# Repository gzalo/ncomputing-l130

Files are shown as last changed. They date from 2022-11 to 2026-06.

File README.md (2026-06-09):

# Ncomputing-L130
The idea of this project is to reverse engineer the Ncomputing L130 PCB (rev 1.3A), to be able to use it as a generic FPGA development board.

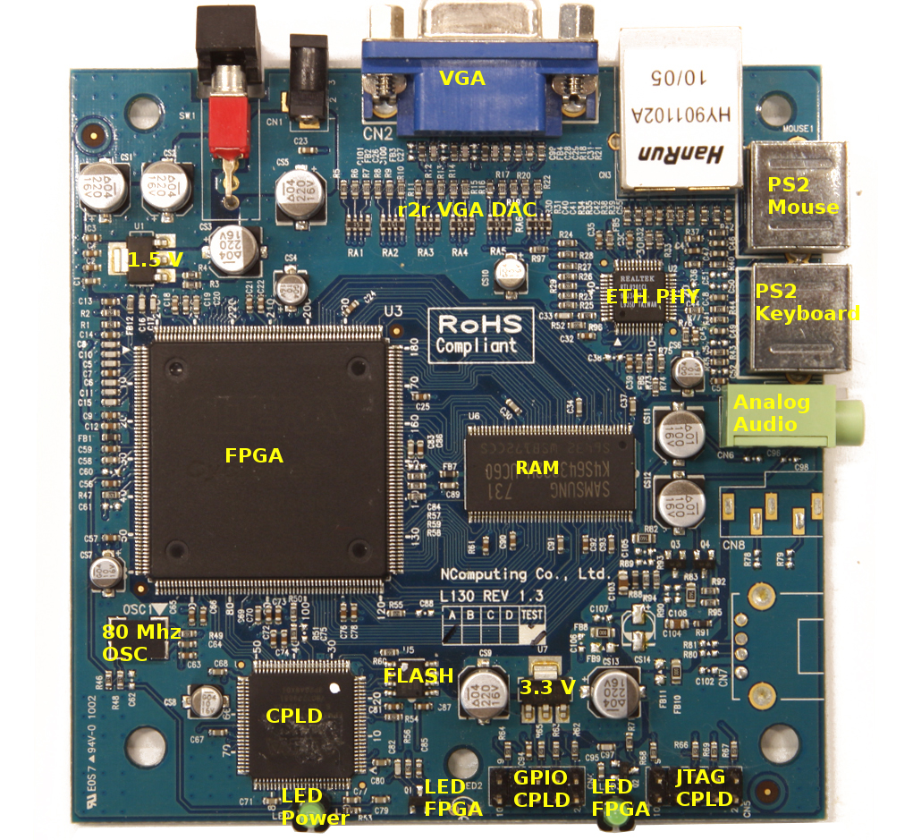
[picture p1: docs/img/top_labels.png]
Labels


Status:
- ✅ [Reverse engineer main components and connections](pcb/)
- ✅ [Basic Blinky test for CPLD](cpld_passthrough/)
- ✅ [Using Passive Serial Configuration for loading FPGA bitstream (CPLD passes through programming signals to FPGA)](cpld_passthrough/)
- ✅ [Reverse engineer full board](pcb/)
- ✅ [Blinky in FPGA](fpga_blink/)
- ✅ [VGA output](fpga_blink/)
- ✅ [Retrocomputing using multicomp](multicomp/)
- ✅ [Program flash memory using external RP2040](rp2040_flash_memory/)
- ✅ [Persist FPGA bitstream in serial flash](cpld_flash_boot/)
- ❌ Serial port 
- ❌ Sound output
- ❌ Keyboard and mouse
- ❌ SDRAM controller
- ❌ Ethernet

# Schematic, component list and PCB photos

[PDF of the Schematic](docs/img/pcb.pdf)

KiCad files can be found in the `pcb/` folder.

[Full component list here (may be missing some values, or have errors)](docs/components.csv)

[PCB Top layer](docs/img/top.jpg) / [PCB Bottom layer](docs/img/bottom.jpg)

# Block diagram

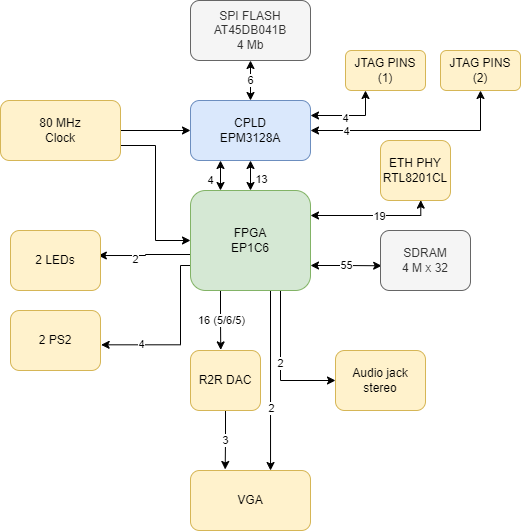
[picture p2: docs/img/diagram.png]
Block diagram


# Projects 

The following folders contain `vhd` files that can be used to create a _Quartus II_ project for this board:
- cpld_passthrough: This generates a CPLD bitstream that makes it work as a passthrough so we can send the signals required for programming the FPGA.
- cpld_flash_boot: This generates a CPLD bitstream that reads an already-programmed AT45DB041B serial flash, configures the FPGA on startup, and then passes the Passive Serial programming header through to the FPGA.
- fpga_blink: Blinks the LEDs that are connected to the FPGA.
- fpga_vga: Generates a 640x480 VGA signal that has some characters of a 32x32 monochromatic font. Uses an internal PLL to convert the 80 MHz clock into the 25 MHz pixel clock required.
- multicomp: Details on mods to Grant Searle's guide to create a retro computer

[Getting started: guide to building the projects and programming the board](docs/getting-started.md)

Newer Windows note: USB Blaster clones no longer work reliably due to driver issues. Using a Windows XP virtual machine with USB passthrough is a better option for programming.

# Flex PCB to add GPIOs
In the [`pin-flex`](pin-flex) folder you can find files to manufacture a very simple flexible PCB that is useful to map out certain unused pins:

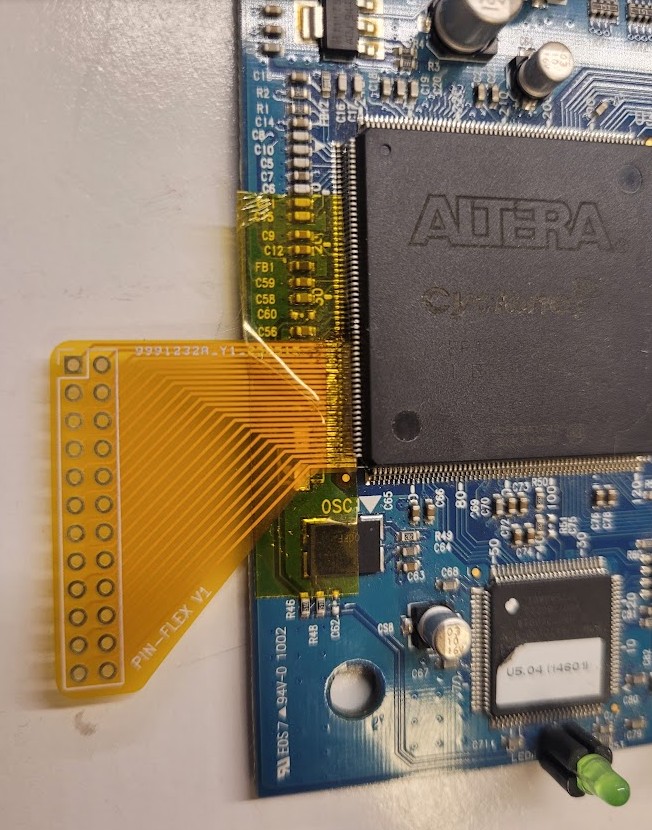
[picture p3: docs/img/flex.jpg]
Flex


To use it, you need to remove R47 and C61, and lift the existing pins using a needle or something similar, while keeping pin 40, 51 and 52 connected to the original board.

# Documentation

The [docs](docs/) folder contains many documents that are useful for this project.

**When using Quartus to generate the bitstream, remember that by default non defined pins are marked as outputs and are LOW. This can cause short circuits and destroy the rest of the circuit. To avoid that, you should go to Assignments->Device->Device and Pin Options...->Unused Pins and set it to "As input tri-stated with weak pull-up". DO THIS FOR BOTH PROJECTS!**

# Thanks to
[Carlos Pantelides (cpantel)](https://github.com/cpantel/)

# Inspirations
- https://github.com/UzixLS/ncomputing-l230

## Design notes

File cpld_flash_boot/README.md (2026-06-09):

# CPLD flash boot

This CPLD image configures the FPGA from the on-board AT45DB041B serial flash at power-up.

The FPGA is still configured in Passive Serial mode. During power-up, the CPLD acts as the configuration controller:

1. Hold `nCONFIG` low while the FPGA finishes power-on reset.
2. Release `nCONFIG`.
3. Send an AT45DB041B continuous array read command from byte address 0.
4. Stream each byte read to the FPGA `DATA0` while clocking `SCK` and `DCLK`, reversing the bit order.
5. Stop when `CONF_DONE` rises, then send a few extra `DCLK` pulses and deselect the flash.
6. Pass the external Passive Serial programming header through to the FPGA so it can still be programmed manually.

The flash is expected to already contain the FPGA bitstream starting at byte address 0. 

## Implementation notes

Use `cpld_flash_boot.vhd` as the Quartus top-level design. Add
`cpld_flash_boot.sdc` to the Quartus project so the clock and multicycle timing
constraints are applied.

The CPLD uses the 80 MHz board clock on pin 87 and drives the AT45DB041B with
the Continuous Array Read, High Frequency Mode command:

```text
0B 00 00 00 00 -> data...
```

The CPLD generates a global clock-enable pulse every 8 cycles of the 80 MHz
input clock. The boot sequencer only advances on that enable. Because `SCK` and
`DCLK` each spend one enable tick low and one enable tick high, the serial
clocks are 5 MHz. The CPLD keeps `nCONFIG` low and leaves the flash deselected
for about 26 ms after startup before issuing the read command. Each flash byte
is read MSB-first from `SO`, then sent to the FPGA `DATA0` LSB-first with
separate `DCLK` pulses. After `CONF_DONE` rises, the CPLD sends 64 extra `DCLK`
pulses, deselects the flash, and switches `DATA0`, `nCONFIG`, `DCLK`, and
open-drain `CONF_DONE` over to the same header pins used by `cpld_passthrough`.

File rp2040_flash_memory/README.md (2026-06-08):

# RP2040 flash programmer

This directory contains a small MicroPython helper for programming the
AT45DB041D SPI flash used by this project.

## Why use the RP2040

Programming this flash with XGecu/TL866II was not reliable. The programmer
detects the memory incorrectly: the first manufacturer/device ID byte is read as
`0x1E` instead of `0x1F`.

Adding resistors and capacitors on the clock and SO lines did not fix the
problem reliably. The programmer also seems to have trouble selecting between
the 256-byte and 264-byte page modes, so programming may work but verifies
incorrectly.

## Programming flow

1. Install MicroPython on the RP2040 board.
2. Copy `flash.py` and the generated `.rbf` file to the RP2040 filesystem.
3. In Quartus, generate the `.rbf` file from the project output:
   `File -> Convert Programming Files`.
4. Open the MicroPython REPL and run:

```python
import flash
flash.program_file("output_file.rbf")
```

The script currently assumes 256-byte page mode (it appears to be the default
in our boards) and uses the pinout documented at the top of `flash.py`.

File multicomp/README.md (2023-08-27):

# Multicomp

[Multicomp is a guide made by Grant Searle](http://searle.x10host.com/Multicomp/index.html) which can be used to create a retrocomputing environment using an FPGA. 
There are a few things that need to be considered when following his guide. I've only tried Z80 with BASIC ROM, and soon I'll likely upload a ready to use version of his code that works with our board.

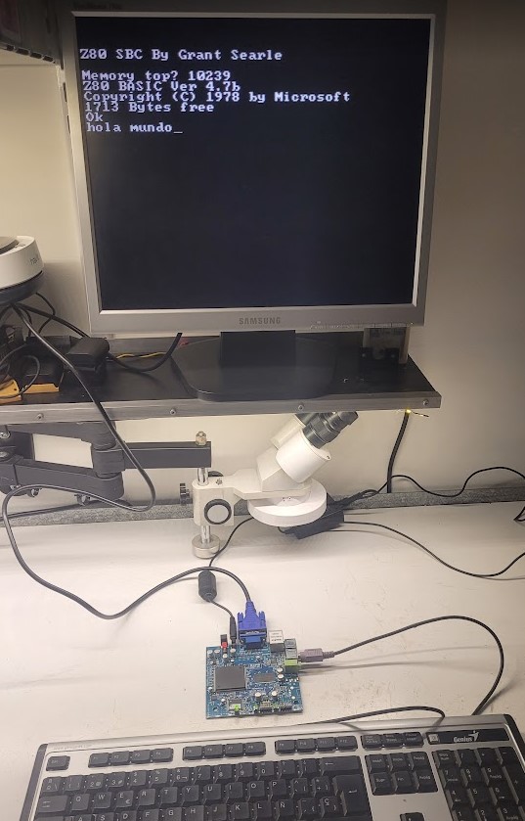
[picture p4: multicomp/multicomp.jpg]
Multicomp working in our board


## Memory
The FPGA he uses has more internal memory (13 KB total vs 10.2 KB in ours) so there are a few things that don't really fit. We need at least:

- 8 KiB for the Z80 BASIC ROM (0x0000-0x2000)
- 1 KiB for the reduced character ROM (128*8 bytes)
- 2 KB for the character video memory (40x25x2 bytes)
- 2 KiB for system RAM that can be used in BASIC (0x2000-0x27FF)

As it can be seen, to fit that minimal system we would need a bigger FPGA, as it sums up to 13 KB. But we can do a trick and split the Z80 ROM into two. First 5120 bytes can be implemented using the internal memory, and the rest of the ROM can be implemented as logic elements. This increases the logic usage a lot (and it takes a lot more time to synthesize too) and it almost doesn't fit, but it works just fine. I had to create a simple program to do this split as it's not supported natively.

Unfortunately our board doesn't have readily available pins for connecting an external static RAM. We could use the external DRAM but it will need an additional controller to use it as a SRAM, still haven't had much time to look into that.

## Cyclone model
Some of his autogenerated VHD files (mostly the ones related to memories) are suited to a Cyclone II board, so they need to change or they won't even compile. Running the IP wizard on those and generating them again should work fine.

## Clock
His design expects the clock to be a 50 MHz signal, so there are a few things that won't work directly unless we change that. The easiest way is to include a PLL that turns the external 80 MHz into the expected one.

## Pins for serial UART
Since we have unused pins, it is possible to connect them to an external UART to use it instead of a keyboard. Since they aren't wired in the board it may be a bit harder to connect to them directly as the FPGA has pins with a 0.5mm pitch. It may be possible to use a modded SMD adapter to do so, lifting the unused pins and soldering them in a board, then fixing that board with resin for mecanical strength (pending investigation).

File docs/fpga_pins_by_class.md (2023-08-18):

# FPGA pins by class

## Audio
- 1
- 2

## Clock
- 28
- 153

## To CPLD (programming)
- 25 (DATA0) to CPLD_68
- 26 (nCONFIG) to CPLD_67
- 36 (DCLK) to CPLD_63 via 82 ohms
- 145 (CONF_DONE) to CPLD_16

## To CPLD (general purpose)
- 73 to CPLD_50
- 74 to CPLD_49
- 79 to CPLD_47
- 80 to CPLD_46
- 81 to CPLD_45
- 83 to CPLD_44
- 86 to CPLD_42
- 87 to CPLD_41
- 88 to CPLD_40
- 94 to CPLD_32
- 95 to CPLD_31
- 96 to CPLD_30
- 97 to CPLD_29

## LEDs
- 85 to LED3
- 93 to LED2

## Ethernet
- 100 to ETH_42 RESETB
- 101 to ETH_46 X1
- 134 to ETH_4 TXD2
- 135 to ETH_5 TXD1
- 136 to ETH_6 TXD0
- 137 to ETH_7 TXC
- 138 to ETH_16 RXC
- 139 to ETH_18 RXD3
- 140 to ETH_19 RXD2
- 141 to ETH_20 RXD1
- 143 to ETH_21 RXD0
- 144 to ETH_22 RXDV
- 156 to ETH_23 CRS
- 180 to ETH_24 FXER/FXEN
- 198 to ETH_3 TXD3
- 199 to ETH_2 TXEN
- 200 to ETH_1 COL
- 201 to ETH_25 MDC
- 202 to ETH_26 MDIO

## RAM
- 177 to MEM_24 A10
- 116 to MEM_66 A9
- 117 to MEM_62 A5
- 118 to MEM_63 A6
- 119 to MEM_65 A8
- 120 to MEM_64 A7
- 121 to MEM_61 A4
- 122 to MEM_60 A3
- 174 to MEM_27 A2
- 175 to MEM_26 A1
- 176 to MEM_25 A0

- 178 to MEM_23 BA1
- 179 to MEM_22 BA0

- 123 to MEM_59 DQM3
- 173 to MEM_28 DQM2
- 114 to MEM_71 DQM1
- 185 to MEM_16 DQM0

- 124 to MEM_56 DQ31
- 125 to MEM_54 DQ30
- 126 to MEM_53 DQ29
- 127 to MEM_51 DQ28
- 128 to MEM_50 DQ27
- 131 to MEM_48 DQ26
- 132 to MEM_47 DQ25
- 133 to MEM_45 DQ24
- 158 to MEM_42 DQ23
- 159 to MEM_40 DQ22
- 160 to MEM_39 DQ21
- 161 to MEM_37 DQ20
- 162 to MEM_36 DQ19
- 163 to MEM_34 DQ18
- 164 to MEM_33 DQ17
- 165 to MEM_31 DQ16
- 102 to MEM_85 DQ15
- 103 to MEM_83 DQ14
- 104 to MEM_82 DQ13
- 105 to MEM_80 DQ12
- 106 to MEM_79 DQ11
- 107 to MEM_77 DQ10
- 108 to MEM_76 DQ9
- 113 to MEM_74 DQ8
- 186 to MEM_13 DQ7
- 187 to MEM_11 DQ6
- 188 to MEM_10 DQ5
- 193 to MEM_8 DQ4
- 194 to MEM_7 DQ3
- 195 to MEM_5 DQ2
- 196 to MEM_4 DQ1
- 197 to MEM_2 DQ0

- 115 to MEM_68 CLK
- 181 to MEM_17 !WE
- 182 to MEM_18 !CAS
- 183 to MEM_19 !RAS
- 184 to MEM_20 !CS

## VGA
- 166 to VGA_B0
- 167 to VGA_B1
- 168 to VGA_B2
- 169 to VGA_B4
- 170 to VGA_B3
- 217 to VGA_R4
- 220 to VGA_R3
- 221 to VGA_R2
- 222 to VGA_R1
- 223 to VGA_R0
- 224 to VGA_G5
- 225 to VGA_G4
- 226 to VGA_G3
- 227 to VGA_G2
- 228 to VGA_G1
- 233 to VGA_G0
- 207 to VGA_HS
- 208 to VGA_VS

## Mouse and Keyboard
- 203 to MOUSE_DATA
- 204 to MOUSE_CLK
- 205 to KBD_CLK
- 206 to KBD_DATA

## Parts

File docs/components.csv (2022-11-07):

Designator | Type | Value
RA1 | Resistor array(x4) | 151
RA2 | Resistor array(x4) | 151
RA3 | Resistor array(x4) | 151
RA4 | Resistor array(x4) | 151
RA5 | Resistor array(x4) | 151
RA6 | Resistor array(x4) | 151
CS1 | Electrolytic capacitor | 220 16v
CS2 | Electrolytic capacitor | 220 16v
CS3 | Electrolytic capacitor | 220 16v
CS4 | Electrolytic capacitor | 10 16v
CS5 | Electrolytic capacitor | 220 16v
CS6 | Electrolytic capacitor | 10 16v
CS7 | Electrolytic capacitor | 10 16v
CS8 | Electrolytic capacitor | 10 16v
CS9 | Electrolytic capacitor | 220 16v
CS10 | Electrolytic capacitor | 10 16v
CS11 | Electrolytic capacitor | 100 16v
CS12 | Electrolytic capacitor | 100 16v
CS13 | Electrolytic capacitor | 220 16v
Q1 | Bipolar Transistor | PNP
Q2 | Bipolar Transistor | PNP
Q3 | Bipolar Transistor | NPN
Q4 | Bipolar Transistor | NPN
FB1 | Ferrite bead
FB2 | Ferrite bead
FB3 | Ferrite bead
FB4 | Ferrite bead
FB5 | Ferrite bead
FB6 | Ferrite bead
FB7 | Ferrite bead
FB8 | Ferrite bead
FB9 | Ferrite bead | Unpopulated
FB10 | Ferrite bead
FB11 | Ferrite bead | Unpopulated
R1 | Resistor | 152
R2 | Resistor | 152
R3 | Resistor | 39X
R4 | Resistor | 10A
R5 | Resistor | 18A
R6 | Resistor | 820
R7 | Resistor | 820
R8 | Resistor | 820
R9 | Resistor | 820
R10 | Resistor | 820
R11 | Resistor | 18A
R12 | Resistor | 820
R13 | Resistor | 820
R14 | Resistor | 820
R15 | Resistor | 820
R16 | Resistor | 18A
R17 | Resistor | 820
R18 | Resistor | 330
R19 | Resistor | 820
R20 | Resistor | 820
R21 | Resistor | 330
R22 | Resistor | 820
R23 | Resistor | 202
R24 | Resistor | 202
R25 | Resistor | 202
R26 | Resistor | 202
R27 | Resistor | 202
R28 | Resistor | 202
R29 | Resistor | 202
R30 | Resistor | 510
R31 | Resistor | 510
R32 | Resistor | 303
R33 | Resistor | 202
R34 | Resistor | 0
R35 | Resistor | 0
R36 | Resistor | Unpopulated
R37 | Resistor | 202
R38 | Resistor | 510
R39 | Resistor | 510
R40 | Resistor | 330
R41 | Resistor | 202
R42 | Resistor | 330
R43 | Resistor | 330
R44 | Resistor | 330
R45 | Resistor | 202
R46 | Resistor | 510
R47 | Resistor | 280
R48 | Resistor | 510
R49 | Resistor | 202
R50 | Resistor | 202
R51 | Resistor | 202
R52 | Resistor | 820
R53 | Resistor | 331
R54 | Resistor | 202
R55 | Resistor | 820
R56 | Resistor | 750
R57 | Resistor | 202
R58 | Resistor | 820
R59 | Resistor | 202
R60 | Resistor | 202
R61 | Capacitor | ?
R62 | Resistor | 202
R63 | Resistor | 202
R64 | Resistor | 202
R65 | Resistor | 202
R66 | Resistor | 202
R67 | Resistor | 202
R68 | Resistor | 202
R69 | Resistor | 202
R70 | ? | Unpopulated
R71 | Resistor | 750
R72 | ? | Unpopulated
R73 | Resistor | 202
R74 | Resistor | 202
R75 | Resistor | 202
R76 | Resistor | 202
R77 | Resistor | 202
R78 | Resistor | Unpopulated
R79 | Resistor | Unpopulated
R80 | Resistor | Unpopulated
R81 | Resistor | Unpopulated
R82 | Resistor | 560
R83 | Resistor | 560
R84 | Resistor | Unpopulated
R85 | Resistor | Unpopulated
R86 | Resistor | Unpopulated
R87 | Resistor | Unpopulated
R88 | INDUCTOR | ?
R89 | Resistor | Unpopulated
R90 | Resistor | Unpopulated
R91 | Resistor | 0
R92 | Resistor | 203
R93 | Resistor | 203
R94 | Resistor | 823
R95 | Resistor | 823
R96 | Resistor | 121
R97 | Resistor | 101
C1 | Capacitor | 10n
C2 | Capacitor | 120n
C3 | Capacitor | 1u
C4 | Capacitor | 120n
C5 | Capacitor | 43p
C6 | Capacitor | 44p
C7 | Capacitor | 100n
C8 | Capacitor | 43p
C9 | Capacitor | 100n
C10 | Capacitor | 44p
C11 | Capacitor | 43p
C12 | Capacitor | 100n
C13 | Capacitor | 2.2u
C14 | Capacitor | 2.2u
C15 | Capacitor | 43p
C16 | Capacitor | 44p
C17 | Capacitor | 44p
C18 | Capacitor | 124n
C19 | Capacitor | 10n
C20 | Capacitor | 10n
C21 | Capacitor | 100n
C22 | Capacitor | 100n
C23 | Capacitor | 124n
C24 | Capacitor | 100n
C25 | Capacitor | 122n
C26 | Capacitor | 30p
C27 | Capacitor | 30p
C28 | Capacitor | 30p
C29 | Capacitor | 316p
C30 | Capacitor | 120n
C31 | Capacitor | Unpopulated?
C32 | Capacitor | 120n
C33 | Capacitor | ?
C34 | Capacitor | 10n
C35 | Capacitor | 120n
C36 | Capacitor | Unpopulated?
C37 | Capacitor | 10n
C38 | Capacitor | Unpopulated?
C39 | Capacitor | 120n
C40 | Capacitor | 120n
C41 | Capacitor | 120n
C42 | Capacitor | 120n
C43 | Capacitor | 120n
C44 | Capacitor | Unpopulated?
C45 | Capacitor | 120n
C46 | Capacitor | 317p
C47 | Capacitor | 315p
C48 | Capacitor | Unpopulated?
C49 | Capacitor | 300p
C50 | Capacitor | 315p
C51 | Capacitor | Unpopulated?
C52 | Capacitor | Unpopulated?
C53 | Capacitor | 120n
C54 | Capacitor | Unpopulated?
C55 | Capacitor | 120n
C56 | Capacitor | Unpopulated?
C57 | Capacitor | 100n
C58 | Capacitor | 100n
C59 | Capacitor | 10n
C60 | Capacitor | 100n
C61 | Capacitor | 100n
C62 | Capacitor | 100n
C63 | Capacitor | 100n
C64 | Capacitor | 10n
C65 | Capacitor | 100n
C66 | Capacitor | 100n
C67 | Capacitor | 100n
C68 | Capacitor | 100n
C69 | Capacitor | 10n
C70 | Capacitor | 100n
C71 | Capacitor | 10n
C72 | Capacitor | 100n
C73 | Capacitor | 100n
C74 | Capacitor | 100n
C75 | Capacitor | Unpopulated?
C76 | Capacitor | 100n
C77 | Capacitor | 160p
C78 | Capacitor | 100n
C79 | Capacitor | 10n
C80 | Capacitor | 10n
C81 | Capacitor | 126n
C82 | Capacitor | 43p
C83 | Capacitor | 10n
C84 | Capacitor | Unpopulated?
C85 | Capacitor | 330p
C86 | Capacitor | 100n
C87 | Capacitor | 123n
C88 | Capacitor | Unpopulated?
C89 | Capacitor | 10n
C90 | Capacitor | Unpopulated?
C91 | Capacitor | 10n
C92 | Capacitor | 120n
C93 | Capacitor | 10n
C94 | Capacitor | ?
C95 | Capacitor | 317p
C96 | Capacitor | Unpopulated?
C97 | Capacitor | 44p
C98 | Capacitor | Unpopulated?
C99 | Capacitor | Unpopulated?
C100 | Capacitor | Unpopulated?
C101 | Capacitor | Unpopulated?
C102 | Capacitor | Unpopulated?
C103 | Capacitor | 2.5u
C104 | Capacitor | Unpopulated?
C105 | Resistor | ?
C106 | Capacitor | Unpopulated?
C107 | Capacitor | Unpopulated?
C108 | Capacitor | 2.5u
SW1 | Power switch
CN1 | Power connector
CN2 | VGA connector
CN3 | RJ45 connector with transformers
MOUSE1 | PS2 mouse connector
KEY1 | PS2 keyboard connector
CN6 | Audio connector
CN8 | Audio connector (not populated)
CN7 | USB connector (not populated)
CN5 | 2x6 connector | JTAG CPLD
CN4 | 2x6 connector | GPIO CPLD
LED1 | Green LED | Power LED
LED2 | Green LED | FPGA controlled LED
LED3 | Green LED | FPGA controlled LED
OSC1 | 80MHz oscillator
U1 | Voltage Regulator | 1117-ADJ
U2 | Ethernet PHY | RTL8201CL
U3 | FPGA | EP1C6Q240C8N
U4 | CPLD | EPM3128ATC100-10N
U5 | SPI Flash | AT45DB041B
U6 | SDRAM | IS42S32400D-7TL
U7 | Voltage Regulator | 1117-3.3

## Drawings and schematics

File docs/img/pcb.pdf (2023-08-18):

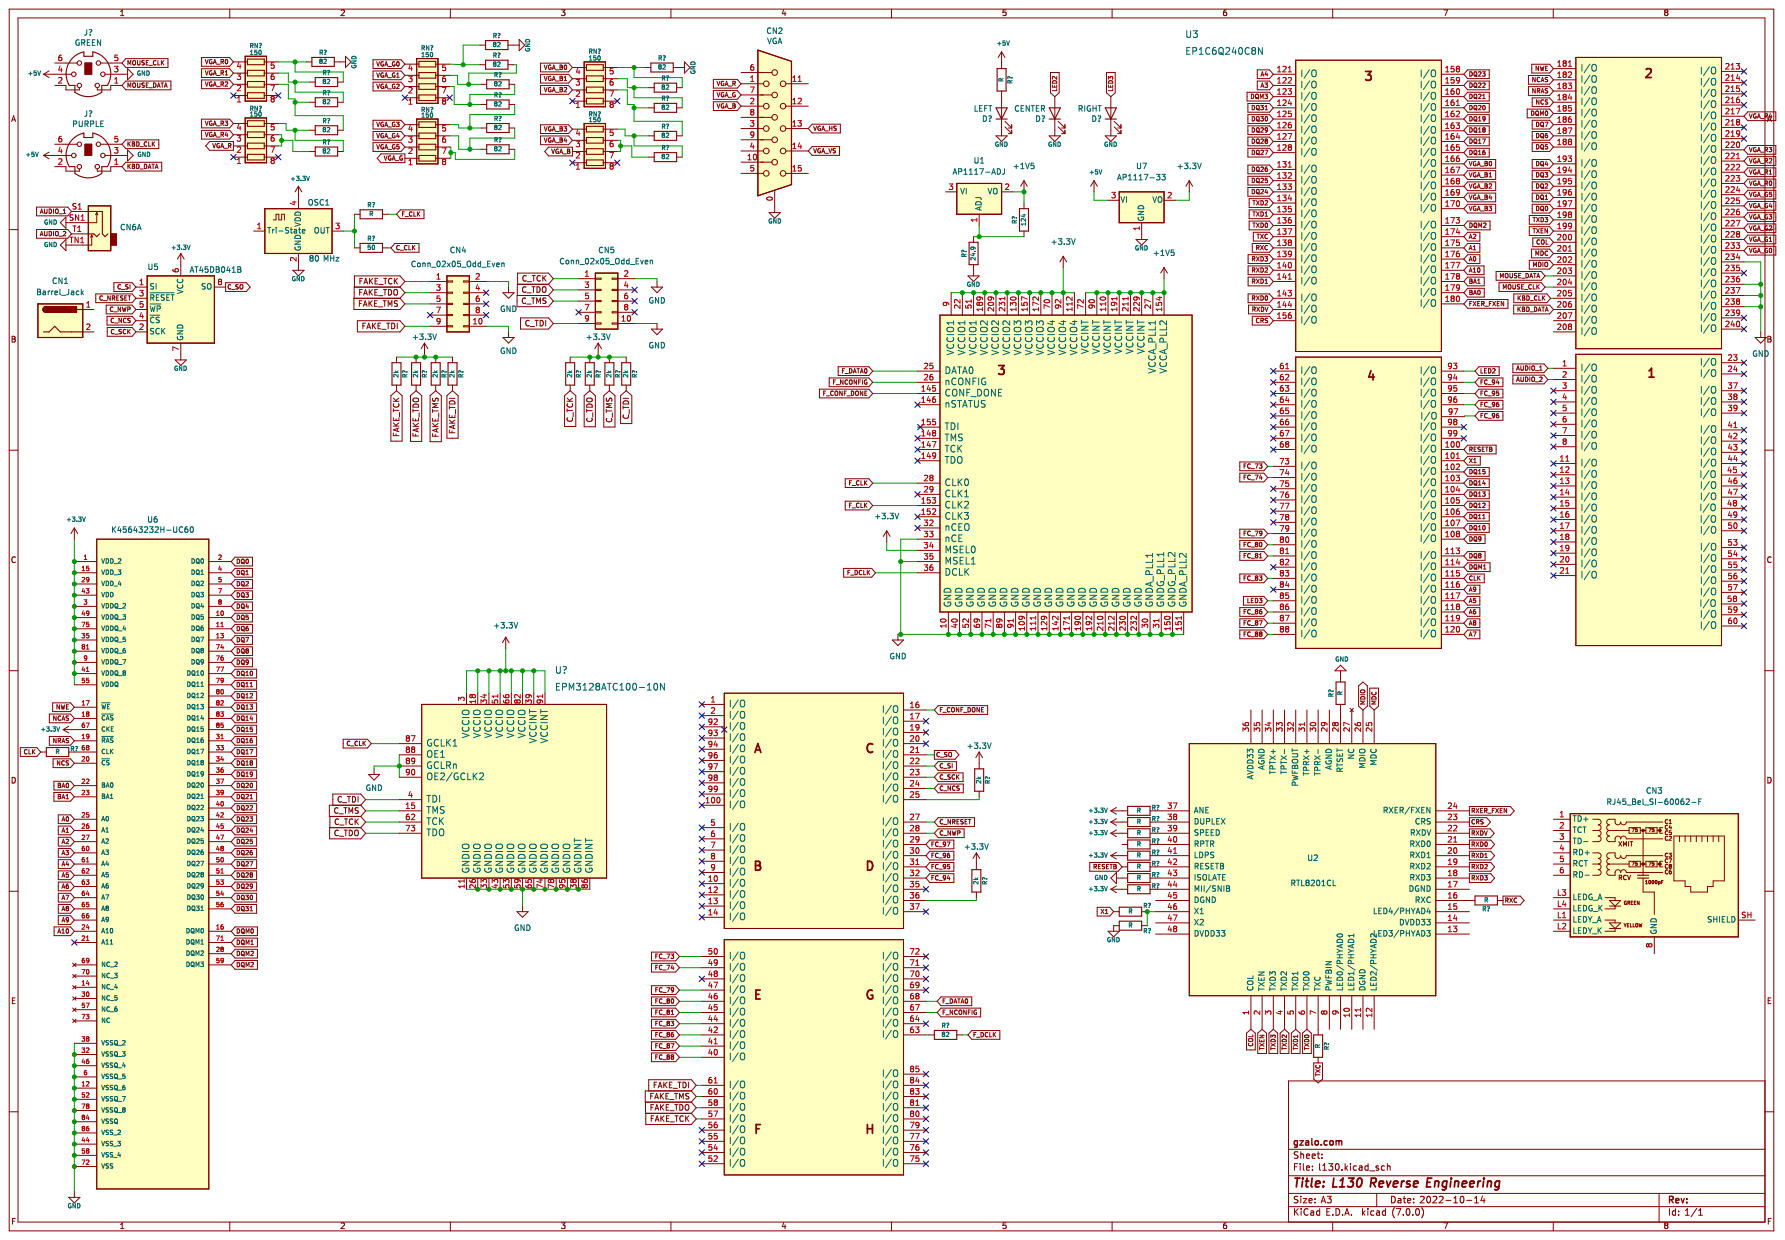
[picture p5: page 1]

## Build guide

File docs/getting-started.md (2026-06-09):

# Requirements
- Ncomputing L130 board
- JTAG programmer: Altera USB Blaster
- Software: Quartus II 13.0sp1 (can be downloaded from Intel website, has Linux support)

Note for newer Windows versions: USB Blaster clones no longer work reliably due to driver issues. Using a Windows XP virtual machine with USB passthrough is a better option for programming.

You need to bridge the pins 5 and 7 of the GPIO CPLD connector (see the picture above) with a 1kΩ resistor. This basically ensures that the nStatus signal follows the nConfig one, and that makes the programmer think that the FPGA is ready to be programmed. You can use a small SMD resistor for this.

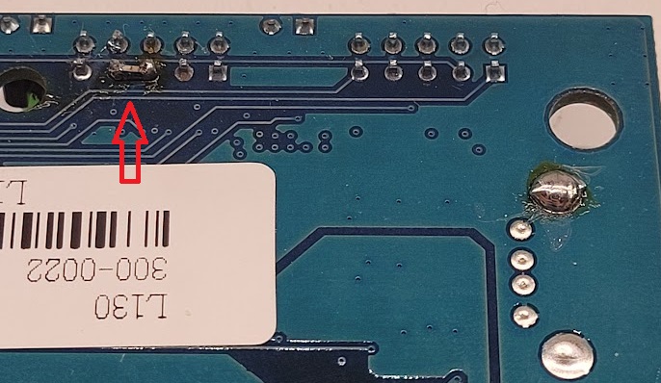
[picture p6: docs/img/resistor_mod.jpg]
Resistor mod


# Building CPLD project

Create a new project in Quartus, pointing to the `cpld_passthrough` folder in the repository. Use that same name for the project name and top-level design:

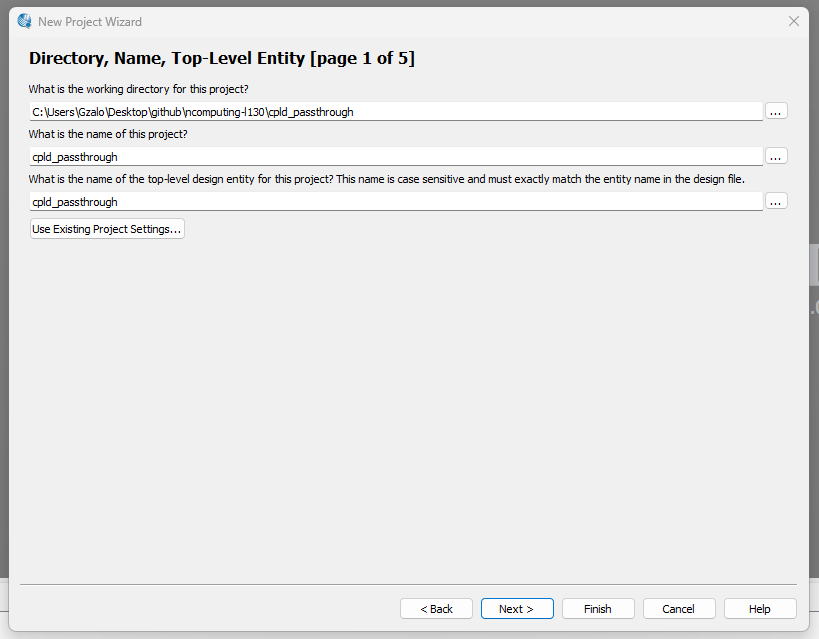
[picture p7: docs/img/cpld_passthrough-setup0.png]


Go to the next step and press `add all`. You should see all three files.

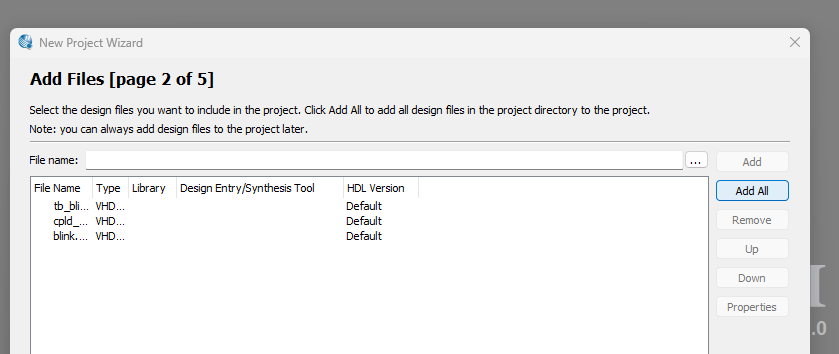
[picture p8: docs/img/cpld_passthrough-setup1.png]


Go to the next step and select the appropiate device: EPM3128ATC100-10 from the MAX3000A family

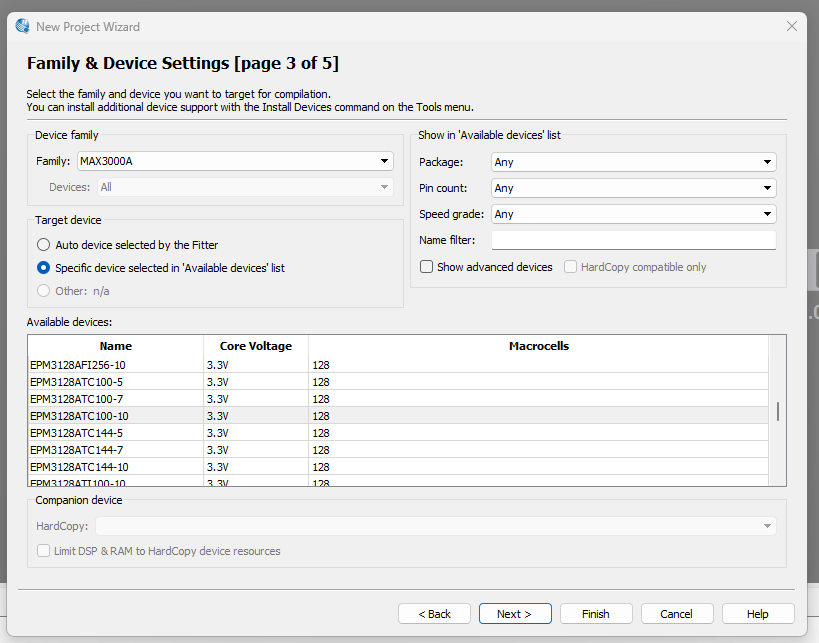
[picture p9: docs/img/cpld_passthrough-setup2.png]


Press `Finish`. Then go to Assignments->Device->Device and Pin Options...->Unused Pins and set it to "As input tri-stated":

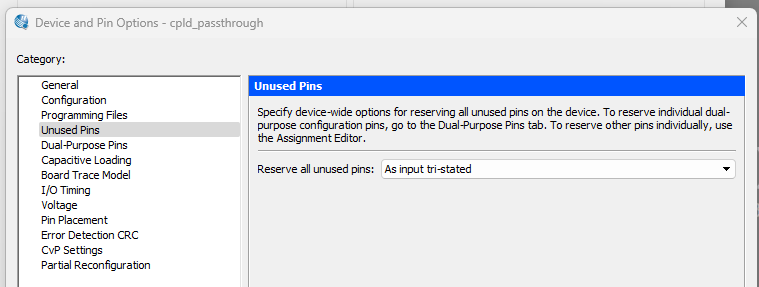
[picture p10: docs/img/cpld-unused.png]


Go to Processing->Start compilation. After a few seconds it should succeed. There may be some warnings (shown as red in the `TimeQuest Timing Analyzer`), they can be ignored.

Go to Assignments->Pin Planner and you should see the following assignments:

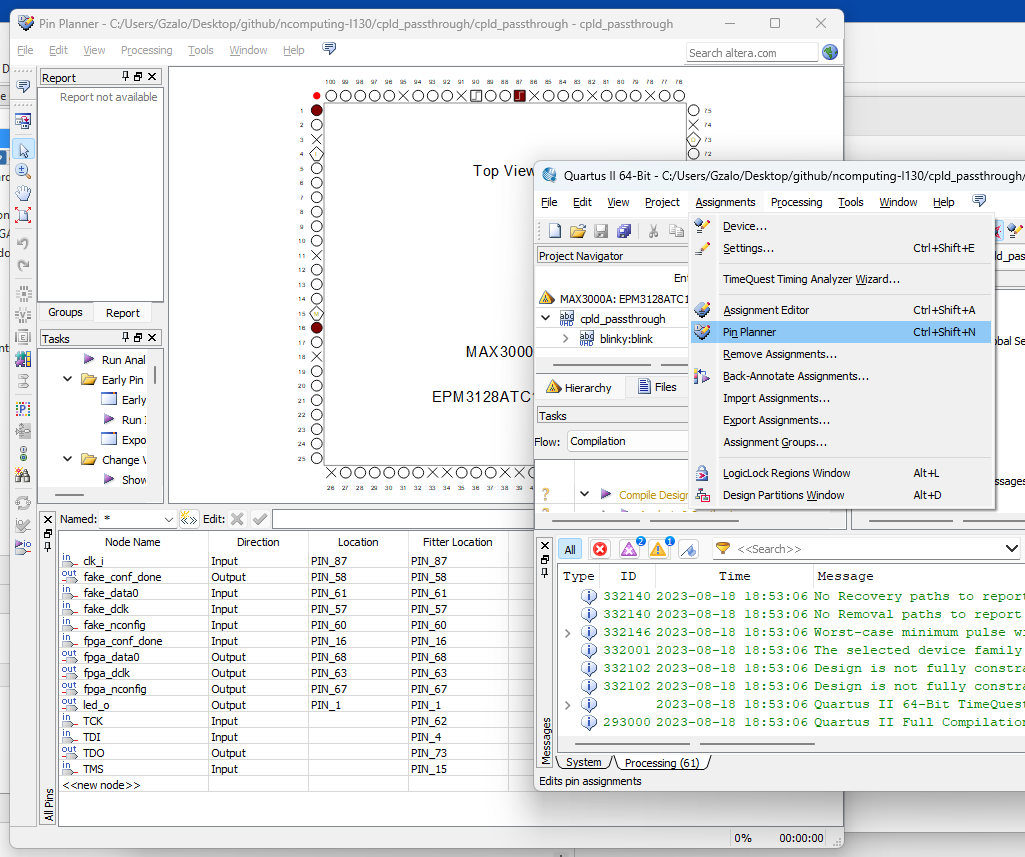
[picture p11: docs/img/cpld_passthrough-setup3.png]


# Programming CPLD

Connect the cable to the connector on the right, keeping in mind the position of pin 1 (red mark of the cable). Then connect the programmer to a computer, connect and power on the board. 

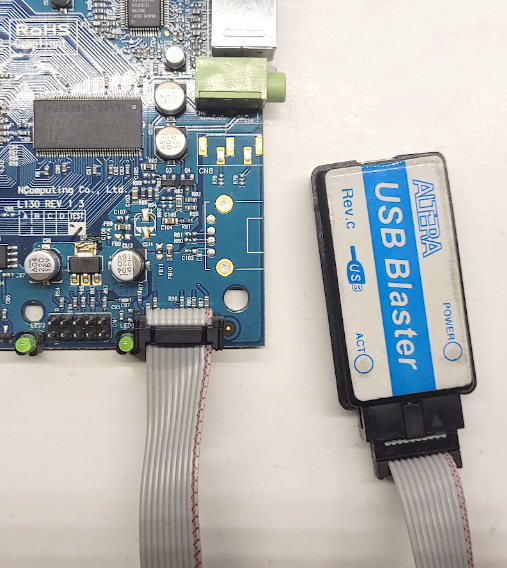
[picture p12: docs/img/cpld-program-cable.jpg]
cpld program cable


Go to Tools->Programmer, press Hardware Setup and select the USB-Blaster hardware. 

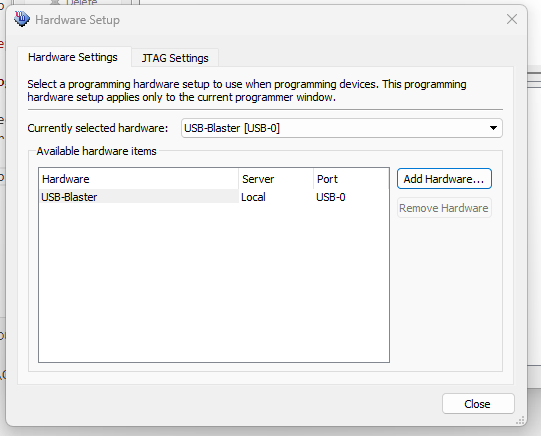
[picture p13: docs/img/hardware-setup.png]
hardware setup


Check the "Program/Configure" checkbox and then press Start

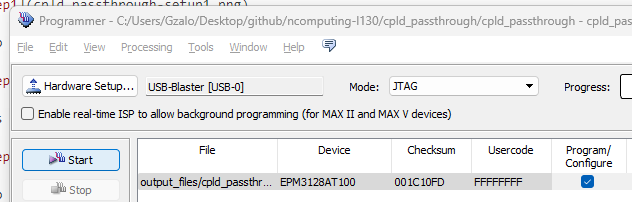
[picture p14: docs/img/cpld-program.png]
cpld program


If everything went ok, it should show a success message:

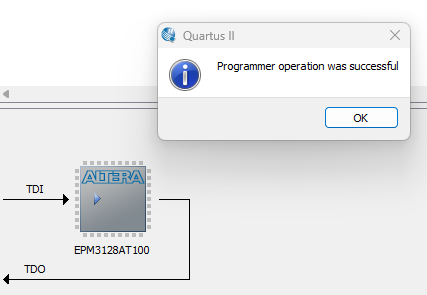
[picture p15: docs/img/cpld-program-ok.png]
cpld program ok


# Building FPGA project

Create a new project in Quartus, pointing to the `fpga_blink` folder in the repository. Use that same name for the project name and top-level design:

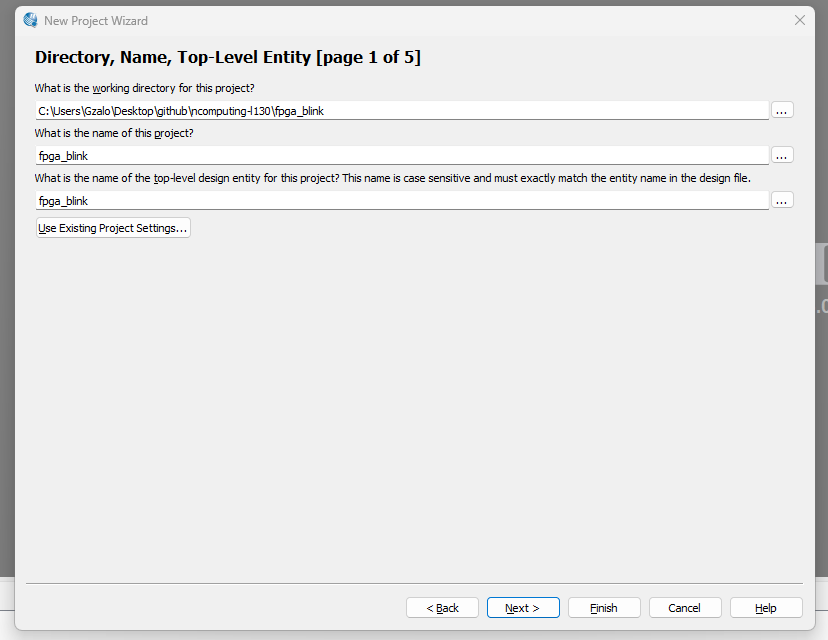
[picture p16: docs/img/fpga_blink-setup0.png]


Go to the next step and press `add all`. You should see all three files.

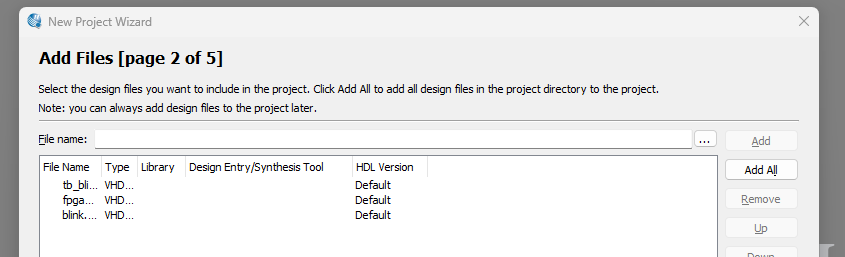
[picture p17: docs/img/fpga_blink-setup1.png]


Go to the next step and select the appropiate device: EP1C6Q240C8 from the Cyclone family

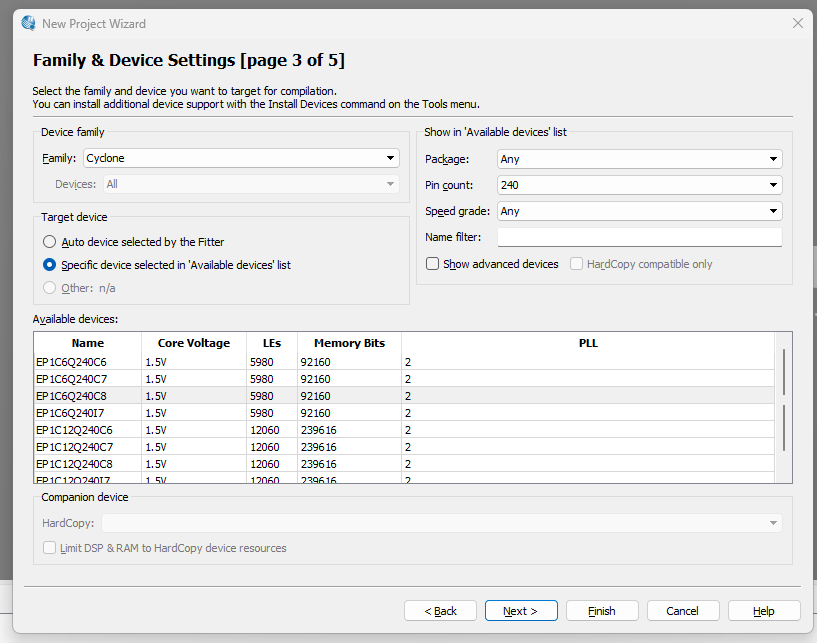
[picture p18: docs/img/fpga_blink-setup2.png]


Press `Finish`. Then go to Assignments->Device->Device and Pin Options...->Unused Pins and set it to "As input tri-stated with weak pull up":

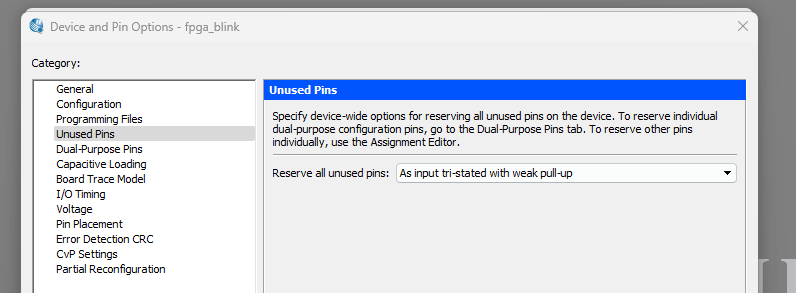
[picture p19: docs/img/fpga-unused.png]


Go to Processing->Start compilation. After a few seconds it should succeed. There may be some warnings (shown as red in the `TimeQuest Timing Analyzer`), they can be ignored.

Go to Assignments->Pin Planner and you should see the following assignments:

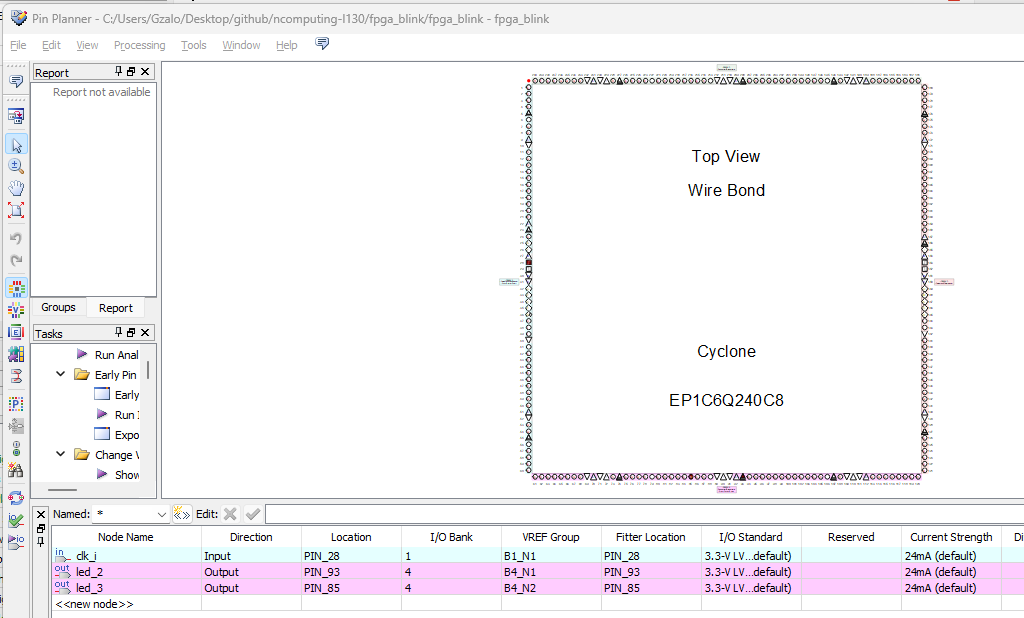
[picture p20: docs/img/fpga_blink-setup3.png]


# Programming FPGA

Connect the cable to the connector on the middle, keeping in mind the position of pin 1 (red mark of the cable). Then connect the programmer to a computer, connect and power on the board. 

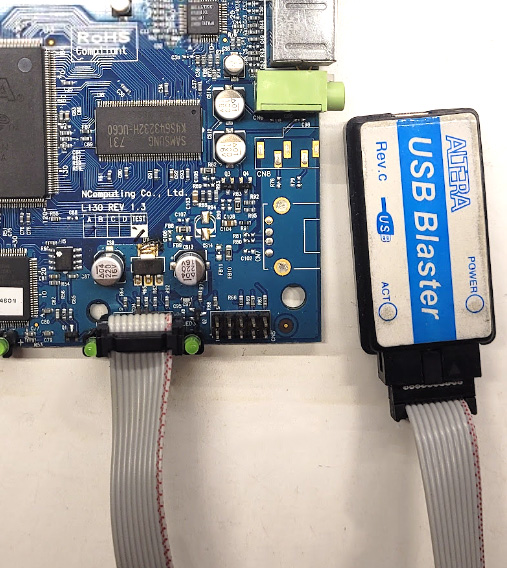
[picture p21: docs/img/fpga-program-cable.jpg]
fpga program cable


Go to Tools->Programmer, press Hardware Setup and select the USB-Blaster hardware. 

hardware setup

Select "Passive Serial" as mode (on the top right) and then press Start

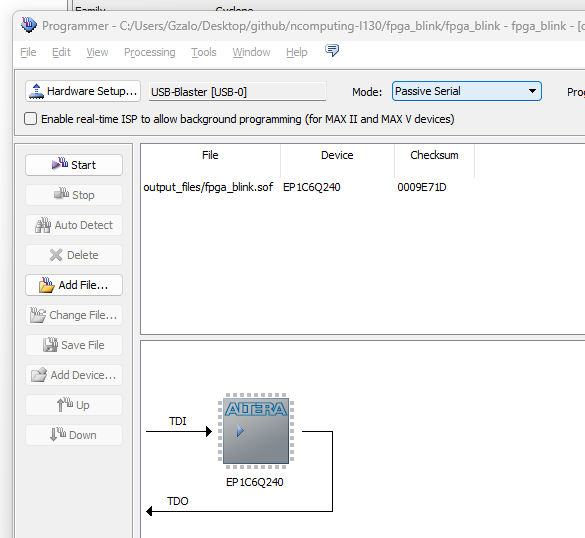
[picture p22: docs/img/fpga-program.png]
fpga program


If everything went ok, it should show a success message, and you should see the blinking LEDs in the board!

# Booting FPGA from serial flash

The `cpld_flash_boot` project is an alternative CPLD image for booting the FPGA from the on-board AT45DB041B flash at startup.

Build it like the `cpld_passthrough` project, using `cpld_flash_boot` as the Quartus project name and top-level design. Keep the same CPLD device, `EPM3128ATC100-10`, and set unused pins to `As input tri-stated`.

This project assumes the flash is already programmed manually. Store the FPGA `.rbf` file starting at flash byte address 0. The CPLD reads the flash with the AT45DB041B continuous array read command, reverses each byte to send Passive Serial data least-significant bit first, clocks it into FPGA `DATA0`, and stops when `CONF_DONE` rises.

After flash boot finishes, the CPLD deselects the flash and passes the external Passive Serial header through to the FPGA, so you can still program the FPGA directly from Quartus without switching back to `cpld_passthrough`.

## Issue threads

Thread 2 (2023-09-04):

Quartus

antibyte, 2023-09-04:
I followed your documentation and got the CPLD flashed.
But then came the problem : Quartus II 13.0 Web Edition does not include support for Cyclone I devices, only the Subscription Edition does.

gzalo, 2023-09-05:
Send me an email: gonzaloavilaalterach@gmail.com and I'll show you some ways to fix that issue

Closed 2023-09-05.

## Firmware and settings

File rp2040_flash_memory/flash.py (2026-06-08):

from machine import Pin, SPI
import time

# RP2040 / Pico        AT45DB041D
# 3V3                 VCC
# GND                 GND
# GP18 SPI0 SCK       SCK
# GP19 SPI0 TX/MOSI   SI
# GP16 SPI0 RX/MISO   SO
# GP17 GPIO           /CS
# 3V3                 /WP  pulled high
# 3V3                 /RESET pulled high

spi = SPI(
    0,
    baudrate=1_000_000,
    polarity=0,
    phase=0,
    bits=8,
    firstbit=SPI.MSB,
    sck=Pin(18),
    mosi=Pin(19),
    miso=Pin(16),
)

cs = Pin(17, Pin.OUT, value=1)

def xfer(tx, rx_len=0):
    """
    Send arbitrary bytes to the AT45DB041D.
    Returns bytes read during optional dummy clocks.
    """
    cs.value(0)
    time.sleep_us(1)

    if tx:
        spi.write(bytes(tx))

    rx = b""
    if rx_len:
        rx = spi.read(rx_len, 0x00)

    time.sleep_us(1)
    cs.value(1) 
    return rx

# AT45DB041D helpers for 256-byte page mode

PAGE_SIZE = 256
NUM_PAGES = 2048          # AT45DB041D: 4 Mbit / 256 bytes = 2048 pages
TOTAL_SIZE = PAGE_SIZE * NUM_PAGES

CMD_STATUS = 0xD7
CMD_BUF1_WRITE = 0x84
CMD_BUF1_TO_PAGE_ERASE = 0x83
CMD_ARRAY_READ_LOW_FREQ = 0x03


def status():
    return xfer([CMD_STATUS], 1)[0]


def wait_ready(verbose=False):
    while True:
        s = status()
        if verbose:
            print("status:", hex(s))
        if s & 0x80:
            return s


def addr24(addr):
    return [
        (addr >> 16) & 0xFF,
        (addr >> 8) & 0xFF,
        addr & 0xFF,
    ]


def page_addr(page, byte_offset=0):
    """
    In 256-byte page mode, the address is linear:
        addr = page * 256 + byte_offset
    """
    if page < 0 or page >= NUM_PAGES:
        raise ValueError("page out of range")
    if byte_offset < 0 or byte_offset >= PAGE_SIZE:
        raise ValueError("byte offset out of range")

    return page * PAGE_SIZE + byte_offset


def buffer1_write(data, offset=0):
    """
    Write up to 256 bytes into SRAM Buffer 1.
    This does not touch flash yet.
    """
    if offset < 0 or offset >= PAGE_SIZE:
        raise ValueError("buffer offset out of range")
    if len(data) + offset > PAGE_SIZE:
        raise ValueError("data too large for buffer")

    # Buffer write command uses 3 address bytes.
    # In practice, for buffer write, only the low byte offset matters in binary mode.
    cmd = [CMD_BUF1_WRITE, 0x00, 0x00, offset & 0xFF]
    xfer(cmd + list(data))


def buffer1_to_page_with_erase(page):
    """
    Program Buffer 1 into main memory page using built-in erase.
    """
    a = page_addr(page, 0)
    xfer([CMD_BUF1_TO_PAGE_ERASE] + addr24(a))
    wait_ready()


def read_array(addr, length):
    """
    Read arbitrary bytes from main memory using low-frequency continuous array read.
    """
    if addr < 0 or addr + length > TOTAL_SIZE:
        raise ValueError("read out of range")

    return xfer([CMD_ARRAY_READ_LOW_FREQ] + addr24(addr), length)


def read_page(page):
    return read_array(page_addr(page), PAGE_SIZE)


def program_page(page, data, pad=True, verify=True):
    """
    Program one 256-byte page.

    If pad=True, shorter pages are padded with 0xFF.
    """
    if len(data) > PAGE_SIZE:
        raise ValueError("page data too large")

    if len(data) < PAGE_SIZE:
        if not pad:
            raise ValueError("page data must be exactly 256 bytes")
        data = data + bytes([0xFF]) * (PAGE_SIZE - len(data))

    wait_ready()

    buffer1_write(data)
    buffer1_to_page_with_erase(page)

    if verify:
        rb = read_page(page)
        if rb != data:
            # Find first mismatch for debugging
            for i, (a, b) in enumerate(zip(data, rb)):
                if a != b:
                    raise RuntimeError(
                        "verify failed at page {}, offset 0x{:02X}: expected 0x{:02X}, got 0x{:02X}".format(
                            page, i, a, b
                        )
                    )
            raise RuntimeError("verify failed at page {}".format(page))

    return True


def program_file(filename, start_page=0, verify=True, max_pages=None):
    """
    Program flash pages from a file stored on the RP2040 filesystem.

    Example:
        program_file("firmware.bin", start_page=0)

    The last partial page is padded with 0xFF.
    """
    page = start_page
    written = 0

    if start_page < 0 or start_page >= NUM_PAGES:
        raise ValueError("start_page out of range")

    with open(filename, "rb") as f:
        while True:
            if max_pages is not None and written >= max_pages:
                break

            chunk = f.read(PAGE_SIZE)
            if not chunk:
                break

            if page >= NUM_PAGES:
                raise RuntimeError("file does not fit in flash")

            print("programming page", page, "file offset", written * PAGE_SIZE)
            program_page(page, chunk, pad=True, verify=verify)

            page += 1
            written += 1

    print("done:", written, "pages,", written * PAGE_SIZE, "bytes allocated in flash")
    return written


CMD_ARRAY_READ_HIGH_FREQ = 0x0B

def read_array_hf(addr, length):
    """
    Continuous Array Read, High Frequency Mode, opcode 0x0B.

    Command format:
        0B A2 A1 A0 00 -> data...
    """
    if addr < 0 or addr + length > TOTAL_SIZE:
        raise ValueError("read out of range")

    # opcode + 24-bit address + one dummy byte
    return xfer([CMD_ARRAY_READ_HIGH_FREQ] + addr24(addr) + [0x00], length)
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

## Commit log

2022-10-25 Initial commit with data
    [l130.kicad_pcb, l130.kicad_sch]
2022-10-25 Add block diagram and PCB photo
2022-11-07 Update top photo without components, update list of components and schematic
    [components.csv, l130.kicad_sch]
2023-08-18 Add more documents
    [l130.kicad_sch, pins_reverse_engineering.ods]
2023-08-18 Complete reverse engineering of board, update schematic
    [l130.kicad_sch, pins_reverse_engineering.ods]
2025-07-04 Add flex pcb, update docs
    [pin-flex-B_Cu.gbr, pin-flex-B_Mask.gbr, pin-flex-B_Paste.gbr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]
